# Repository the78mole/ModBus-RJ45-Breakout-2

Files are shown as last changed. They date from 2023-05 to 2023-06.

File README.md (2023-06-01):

# Modbus-RJ45-Breakout
A breakout board for Dual-ModBus-over-Twisted-Pair (RJ45) with isolated converters option

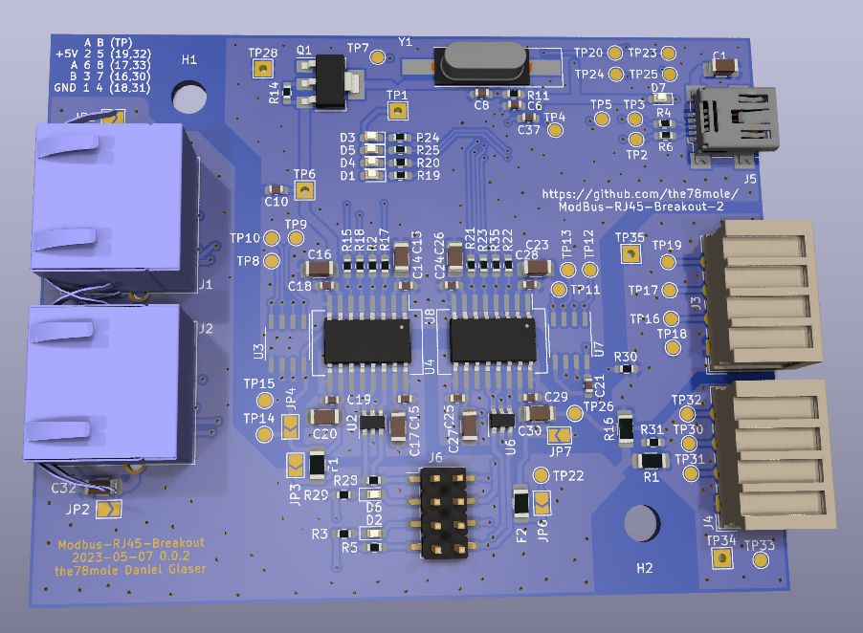
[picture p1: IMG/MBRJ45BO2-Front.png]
Front

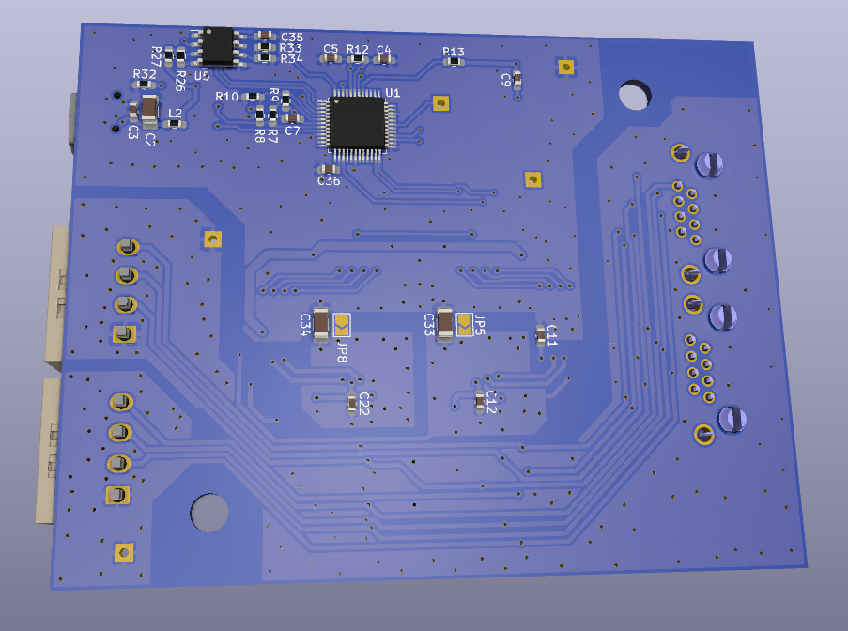
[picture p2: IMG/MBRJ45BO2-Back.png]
Back


Here are some images of the first prototype, assembled with isolating RS485 transceivers. Echo already works, real testing on a ModBus will take place soon.

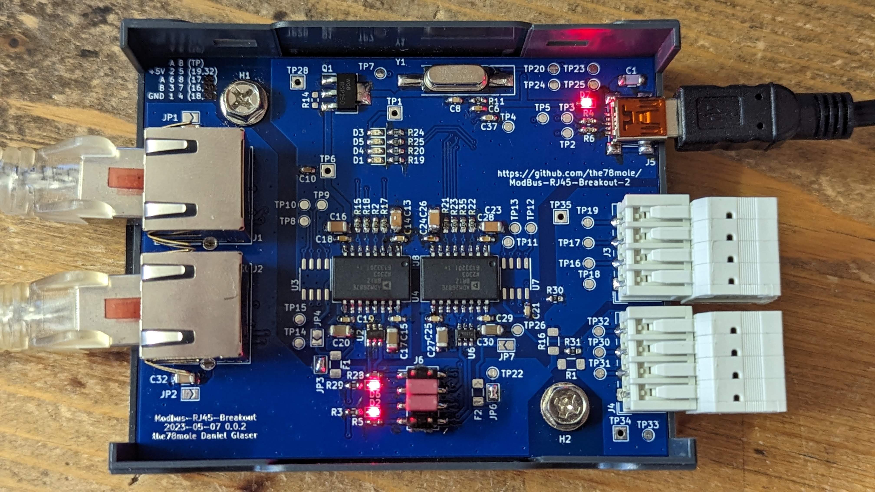
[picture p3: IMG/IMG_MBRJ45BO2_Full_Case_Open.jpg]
Full Case Open

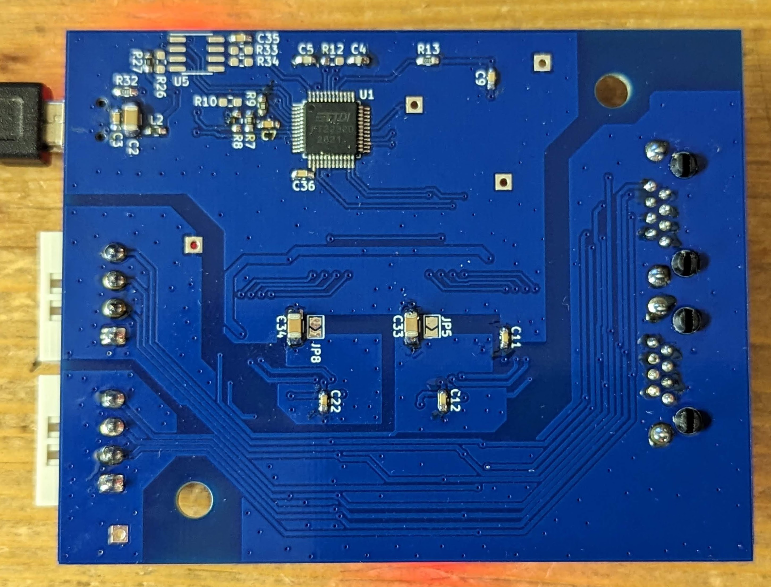
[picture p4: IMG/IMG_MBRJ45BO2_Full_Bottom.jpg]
Full Bottom

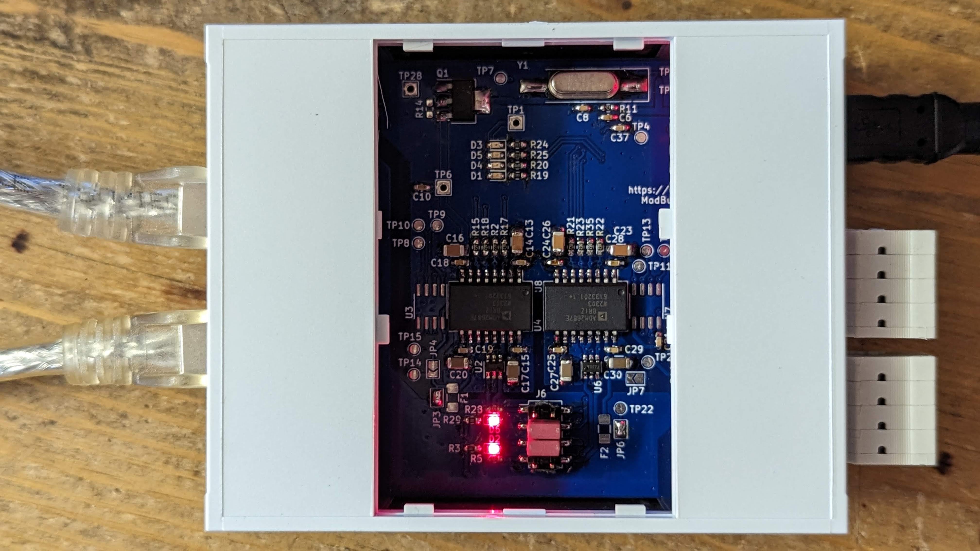
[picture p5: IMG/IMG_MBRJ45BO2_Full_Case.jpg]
Full Case Closed


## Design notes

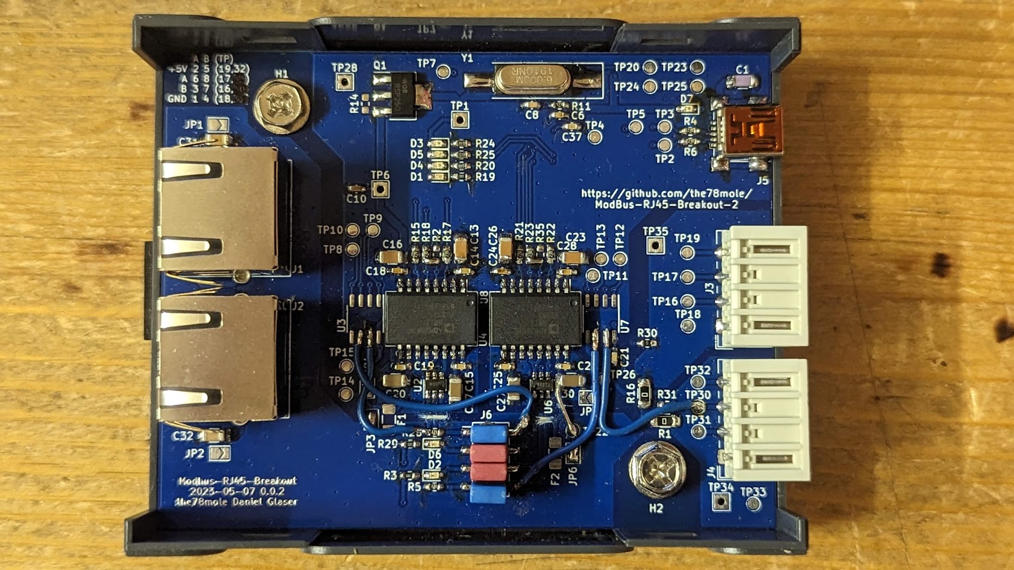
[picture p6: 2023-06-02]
IMG/IMG_MBRJ45BO2_Full_Case_Open-Fixed.jpg

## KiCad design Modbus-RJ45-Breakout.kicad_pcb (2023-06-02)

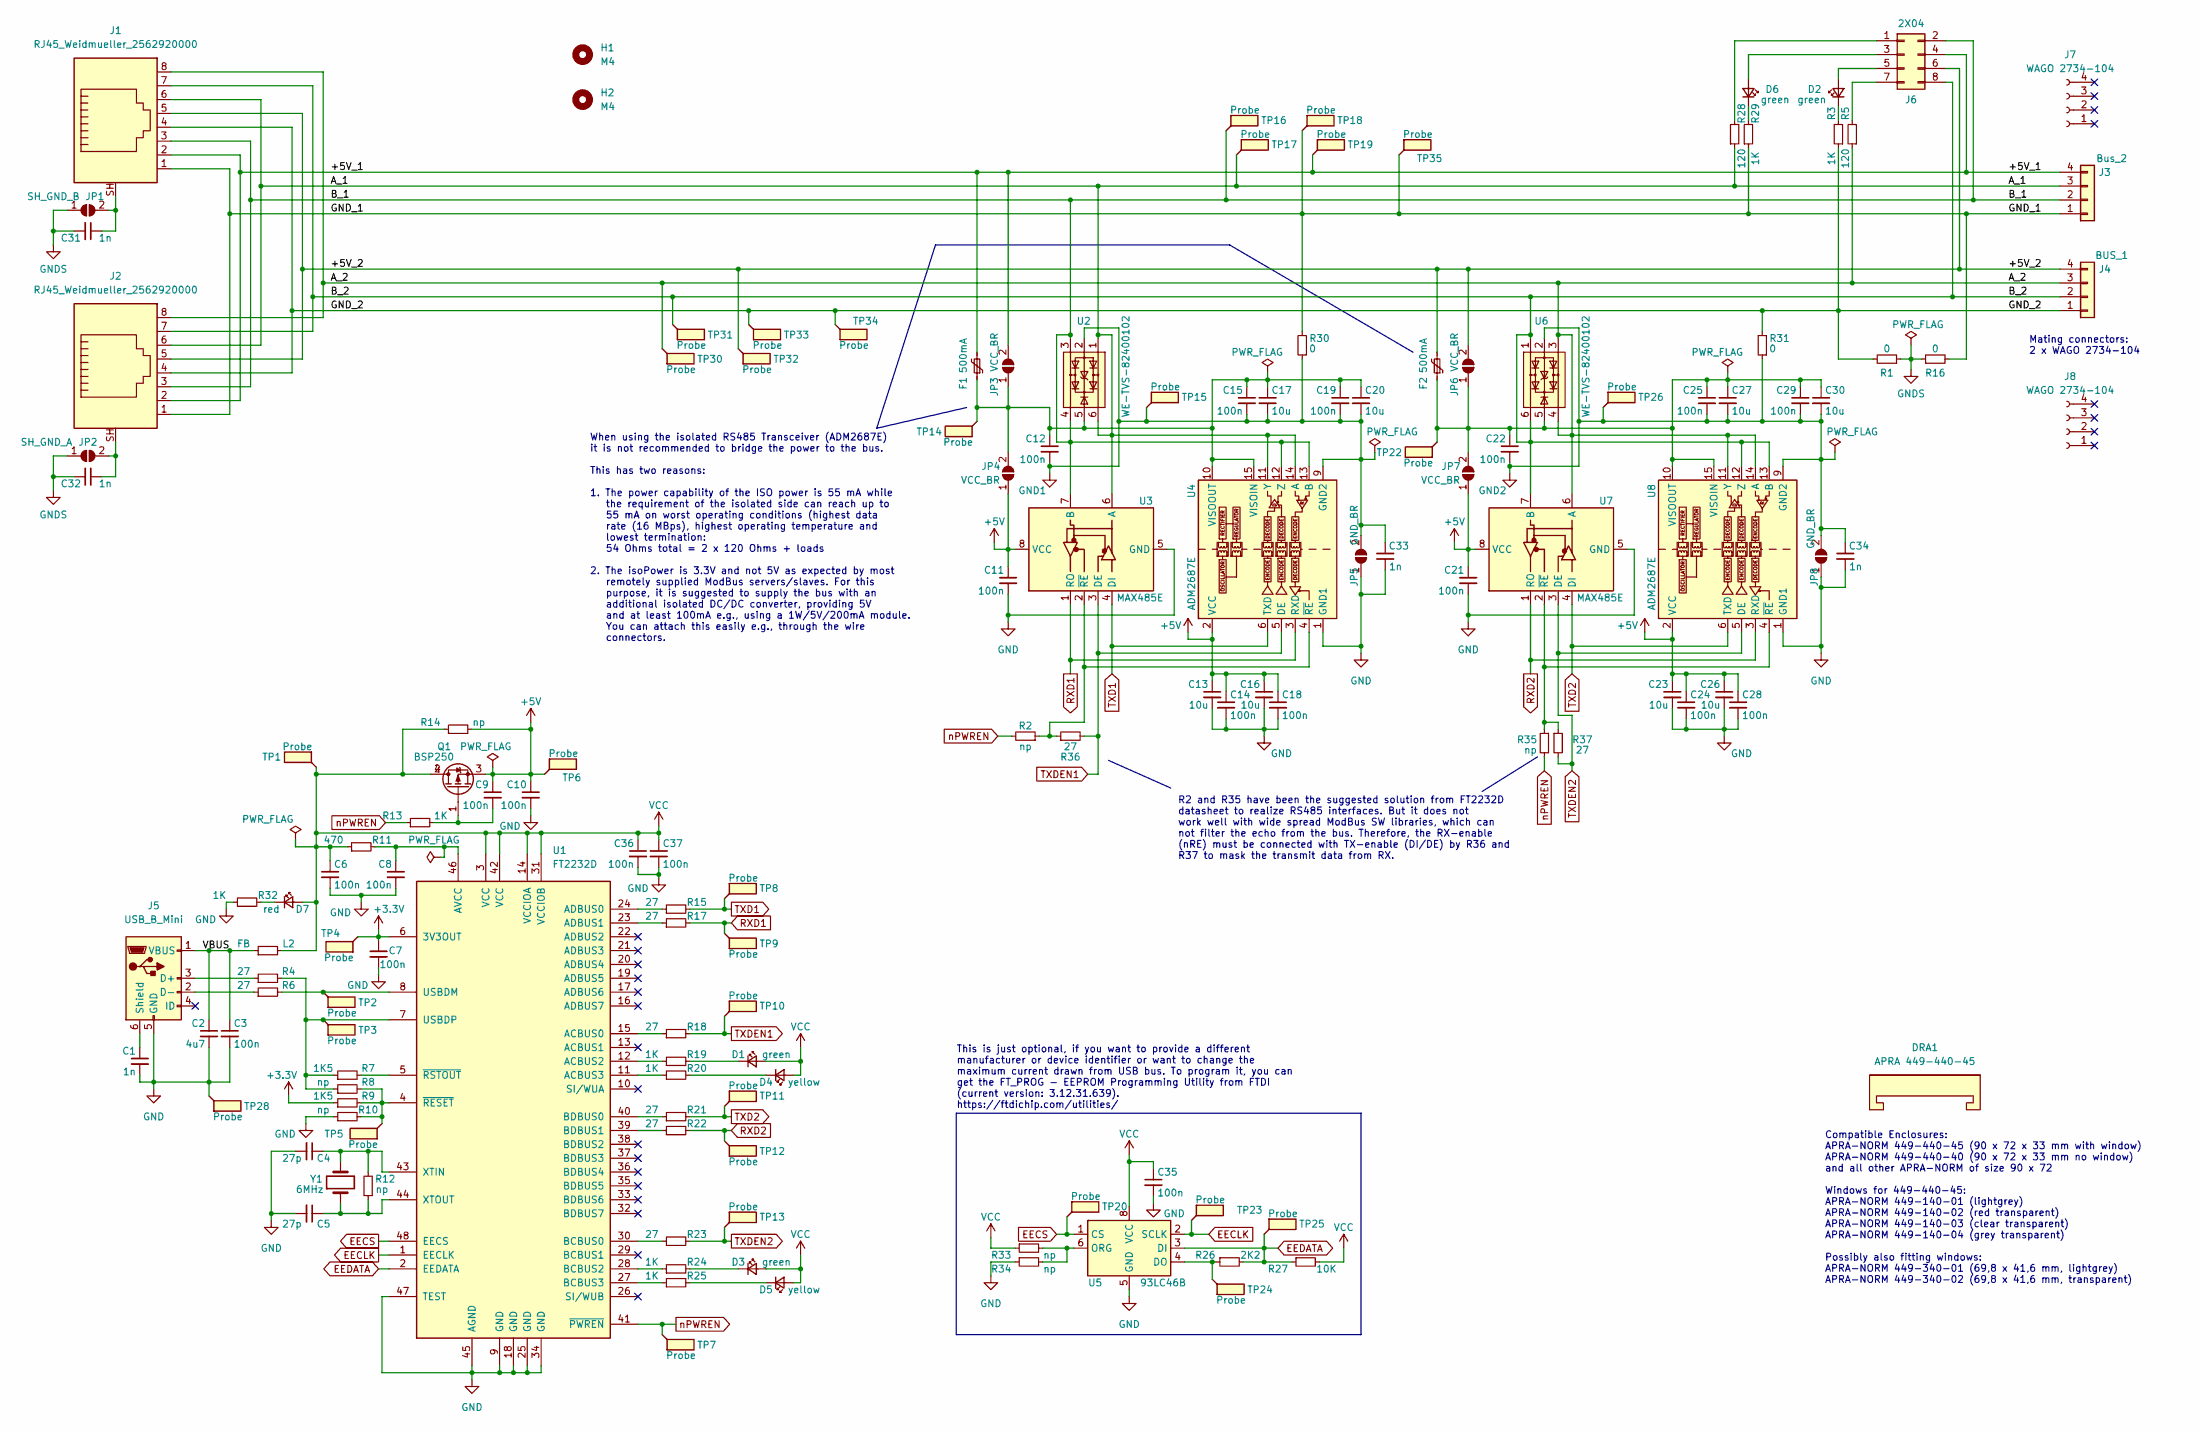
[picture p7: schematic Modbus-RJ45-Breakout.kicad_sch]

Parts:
C1, C31, C32, C33, C34: 1n; C_1206_3216Metric_Pad1.33x1.80mm_HandSolder
C2: 4u7; C_1206_3216Metric_Pad1.33x1.80mm_HandSolder
C3, C6, C7, C8, C9, C10, C11, C12, C14, C15, C18, C19, C21, C22, C24, C25, C28, C29, C35, C36, C37: 100n; C_0603_1608Metric_Pad1.08x0.95mm_HandSolder
C4, C5: 27p; C_0603_1608Metric_Pad1.08x0.95mm_HandSolder
C13, C16, C17, C20, C23, C26, C27, C30: 10u; C_1206_3216Metric_Pad1.33x1.80mm_HandSolder
D1, D2, D3, D6: green; LED_0603_1608Metric_Pad1.05x0.95mm_HandSolder
D4, D5: yellow; LED_0603_1608Metric_Pad1.05x0.95mm_HandSolder
D7: red; LED_0603_1608Metric_Pad1.05x0.95mm_HandSolder
DRA1: APRA 449-440-45; Dummy_0; MPN 449-440-45
F1, F2: 500mA; Fuse_1206_3216Metric_Pad1.42x1.75mm_HandSolder
H1, H2: M4; MountingHole_4.3mm_M4_DIN965
J1, J2: RJ45_Weidmueller_2562920000; RJ45_Weidmüller_2562920000_Horizontal
J3: Bus_2; Wago_734-164_1x04_P3.50mm_Horizontal
J4: BUS_1; Wago_734-164_1x04_P3.50mm_Horizontal
J5: USB_B_Mini; USB_Mini-B_Wuerth_65100516121_Horizontal
J6: 2X04; PinHeader_2x04_P2.54mm_Vertical_SMD
J7, J8: WAGO 2734-104; Dummy_0; MPN 2734-104
JP1: SH_GND_B; SolderJumper-2_P1.3mm_Open_TrianglePad1.0x1.5mm
JP2: SH_GND_A; SolderJumper-2_P1.3mm_Open_TrianglePad1.0x1.5mm
JP3, JP4, JP6, JP7: VCC_BR; SolderJumper-2_P1.3mm_Open_TrianglePad1.0x1.5mm
JP5, JP8: GND_BR; SolderJumper-2_P1.3mm_Open_TrianglePad1.0x1.5mm
L2: FB; R_0603_1608Metric_Pad0.98x0.95mm_HandSolder
Q1: BSP250; SOT-223
R1, R16: 0; R_1206_3216Metric_Pad1.30x1.75mm_HandSolder
R2, R8, R10, R12, R14, R33, R34, R35: np; R_0603_1608Metric_Pad0.98x0.95mm_HandSolder
R3, R13, R19, R20, R24, R25, R29, R32: 1K; R_0603_1608Metric_Pad0.98x0.95mm_HandSolder
R4, R6, R15, R17, R18, R21, R22, R23, R36, R37: 27; R_0603_1608Metric_Pad0.98x0.95mm_HandSolder
R5, R28: 120; R_0603_1608Metric_Pad0.98x0.95mm_HandSolder
R7, R9: 1K5; R_0603_1608Metric_Pad0.98x0.95mm_HandSolder
R11: 470; R_0603_1608Metric_Pad0.98x0.95mm_HandSolder
R26: 2K2; R_0603_1608Metric_Pad0.98x0.95mm_HandSolder
R27: 10K; R_0603_1608Metric_Pad0.98x0.95mm_HandSolder
R30, R31: 0; R_0603_1608Metric_Pad0.98x0.95mm_HandSolder
TP1, TP6, TP28, TP34, TP35: Probe; TestPoint_THTPad_2.0x2.0mm_Drill1.0mm
TP2, TP3, TP4, TP5, TP7, TP8, TP9, TP10, TP11, TP12, TP13, TP14, TP15, TP16, TP17, TP18, TP19, TP20, TP22, TP23, TP24, TP25, TP26, TP30, TP31, TP32, TP33: Probe; TestPoint_Pad_D1.5mm
U1: FT2232D; LQFP-48_7x7mm_P0.5mm
U2, U6: WE-TVS-82400102; SOT-23-6
U3, U7: MAX485E; SO-8_3.9x4.9mm_P1.27mm
U4, U8: ADM2687E; SOIC-16W_7.5x12.8mm_P1.27mm
U5: 93LC46B; SOIC-8_3.9x4.9mm_P1.27mm
Y1: 6MHz; Crystal_SMD_HC49-SD_HandSoldering

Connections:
+3V3: C7.1, R9.1, TP4.1, U1.6 (3V3OUT)
+5V: C9.1, C10.1, C11.1, C13.1, C14.1, C16.1, C18.1, C21.1, C23.1, C24.1, C26.1, C28.1, JP4.1 (A), JP7.1 (A), Q1.3 (S), R14.2, TP6.1, U3.8 (VCC), U4.2 (VCC), U4.7 (VCC), U7.8 (VCC), U8.2 (VCC), U8.7 (VCC)
/+5V_1: F1.2, J1.2, J2.2, J3.4, J6.4, JP3.2 (B), TP19.1
/+5V_2: F2.2, J1.5, J2.5, J4.4, J6.6, JP6.2 (B), TP32.1
/A_1: J1.6, J2.6, J3.3, R28.1, TP17.1, U2.1, U2.6, U3.6 (A), U4.11 (Y), U4.14 (A)
/A_2: J1.8, J2.8, J4.3, R5.1, TP30.1, U6.3, U6.4, U7.6 (A), U8.11 (Y), U8.14 (A)
/B_1: J1.3, J2.3, J3.2, J6.2, TP16.1, U2.3, U2.4, U3.7 (B), U4.12 (Z), U4.13 (B)
/B_2: J1.7, J2.7, J4.2, J6.8, TP31.1, U6.1, U6.6, U7.7 (B), U8.12 (Z), U8.13 (B)
/GND_1: J1.1, J2.1, J3.1, R16.2, R29.1, R30.2, TP18.1, TP35.1
/GND_2: J1.4, J2.4, J4.1, R1.2, R3.1, R31.2, TP33.1, TP34.1
/VBUS: C2.1, C3.1, J5.1 (VBUS), L2.1
EECLK: TP23.1, U1.1 (EECLK), U5.2 (SCLK)
EECS: TP20.1, U1.48 (EECS), U5.1 (CS)
EEDATA: R26.2, R27.1, TP25.1, U1.2 (EEDATA), U5.3 (DI)
GND: C1.2, C2.2, C3.2, C4.2, C5.2, C6.2, C7.2, C8.2, C10.2, C11.2, C13.2, C14.2, C16.2, C18.2, C21.2, C23.2, C24.2, C26.2, C28.2, C33.2, C34.2, C35.2, C36.2, C37.2, J5.5 (GND), JP5.1 (A), JP8.1 (A), R10.1, R32.1, R34.1, TP28.1, U1.9 (GND), U1.18 (GND), U1.25 (GND), U1.34 (GND), U1.45 (AGND), U1.47 (TEST), U3.5 (GND), U4.1 (GND1), U4.8 (GND1), U5.5 (GND), U7.5 (GND), U8.1 (GND1), U8.8 (GND1)
GND1: C12.2, C15.2, C17.2, C19.2, C20.2, C33.1, JP5.2 (B), R30.1, TP15.1, U2.2, U4.9 (GND2), U4.16 (GND2)
GND2: C22.2, C25.2, C27.2, C29.2, C30.2, C34.1, JP8.2 (B), R31.1, TP26.1, U6.2, U8.9 (GND2), U8.16 (GND2)
GNDS: C31.2, C32.2, JP1.1 (A), JP2.1 (A), R1.1, R16.1
unnamed: C1.1, J5.6 (Shield)
unnamed: C4.1, R12.2, U1.43 (XTIN), Y1.2
unnamed: C5.1, R12.1, U1.44 (XTOUT), Y1.1
unnamed: C8.1, R11.2, U1.46 (AVCC)
unnamed: C9.2, Q1.1 (D), R13.2
unnamed: C12.1, C15.1, C17.1, C19.1, C20.1, F1.1, JP3.1 (A), JP4.2 (B), TP14.1, U2.5, U4.10 (VISOOUT), U4.15 (VISOIN)
unnamed: C22.1, C25.1, C27.1, C29.1, C30.1, F2.1, JP6.1 (A), JP7.2 (B), TP22.1, U6.5, U8.10 (VISOOUT), U8.15 (VISOIN)
unnamed: C31.1, J1.SH, JP1.2 (B)
unnamed: C32.1, J2.SH, JP2.2 (B)
unnamed: D1.1 (K), R19.2
unnamed: D2.1 (K), R3.2
unnamed: D2.2 (A), J6.5
unnamed: D3.1 (K), R24.2
unnamed: D4.1 (K), R20.2
unnamed: D5.1 (K), R25.2
unnamed: D6.1 (K), R29.2
unnamed: D6.2 (A), J6.3
unnamed: D7.1 (K), R32.2
unnamed: J5.2 (D-), R6.1
unnamed: J5.3 (D+), R4.1
unnamed: J6.1, R28.2
unnamed: J6.7, R5.2
unnamed: R2.1, R36.1, U3.2 (~RE), U4.4 (~RE)
unnamed: R4.2, R7.1, R8.1, TP3.1, U1.7 (USBDP)
unnamed: R6.2, TP2.1, U1.8 (USBDM)
unnamed: R7.2, U1.5 (~RSTOUT)
unnamed: R8.2, R9.2, R10.2, TP5.1, U1.4 (~RESET)
unnamed: R15.1, U1.24 (ADBUS0)
unnamed: R17.1, U1.23 (ADBUS1)
unnamed: R18.1, U1.15 (ACBUS0)
unnamed: R19.1, U1.12 (ACBUS2)
unnamed: R20.1, U1.11 (ACBUS3)
unnamed: R21.1, U1.40 (BDBUS0)
unnamed: R22.1, U1.39 (BDBUS1)
unnamed: R23.1, U1.30 (BCBUS0)
unnamed: R24.1, U1.28 (BCBUS2)
unnamed: R25.1, U1.27 (BCBUS3)
unnamed: R26.1, TP24.1, U5.4 (DO)
unnamed: R33.2, R34.2, U5.6 (ORG)
unnamed: R35.1, R37.1, U7.2 (~RE), U8.4 (~RE)
RXD1: R17.2, TP9.1, U3.1 (RO), U4.3 (RXD)
RXD2: R22.2, TP12.1, U7.1 (RO), U8.3 (RXD)
TXD1: R15.2, TP8.1, U3.4 (DI), U4.6 (TXD)
TXD2: R21.2, TP11.1, U7.4 (DI), U8.6 (TXD)
TXDEN1: R18.2, R36.2, TP10.1, U3.3 (DE), U4.5 (DE)
TXDEN2: R23.2, R37.2, TP13.1, U7.3 (DE), U8.5 (DE)
VCC: C6.1, C35.1, C36.1, C37.1, D1.2 (A), D3.2 (A), D4.2 (A), D5.2 (A), D7.2 (A), L2.2, Q1.2 (G), Q1.4 (G), R11.1, R14.1, R27.2, R33.1, TP1.1, U1.3 (VCC), U1.14 (VCCIOA), U1.31 (VCCIOB), U1.42 (VCC), U5.8 (VCC)
nPWREN: R2.2, R13.1, R35.2, TP7.1, U1.41 (~PWREN)

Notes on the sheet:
Compatible Enclosures: APRA-NORM 449-440-45 (90 x 72 x 33 mm with window) APRA-NORM 449-440-40 (90 x 72 x 33 mm no window) and all other APRA-NORM of size 90 x 72 Windows for 449-440-45: APRA-NORM 449-140-01 (lightgrey) APRA-NORM 449-140-02 (red transparent) APRA-NORM 449-140-03 (clear transparent)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
When using the isolated RS485 Transceiver (ADM2687E) it is not recommended to bridge the power to the bus. This has two reasons: 1. The power capability of the ISO power is 55 mA while the requirement of the isolated side can reach up to 55 mA on worst operating conditions (highest data rate (16 MB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
Mating connectors: 2 x WAGO 2734-104
This is just optional, if you want to provide a different manufacturer or device identifier or want to change the maximum current drawn from USB bus. To program it, you can get the FT_PROG - EEPROM Programming Utility from FTDI (current version: 3.12.31.639). https://ftdichip.com/utilities/
R2 and R35 have been the suggested solution from FT2232D datasheet to realize RS485 interfaces. But it does not work well with wide spread ModBus SW libraries, which can not filter the echo from the bus. Therefore, the RX-enable (nRE) must be connected with TX-enable (DI/DE) by R36 and R37 to mask 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

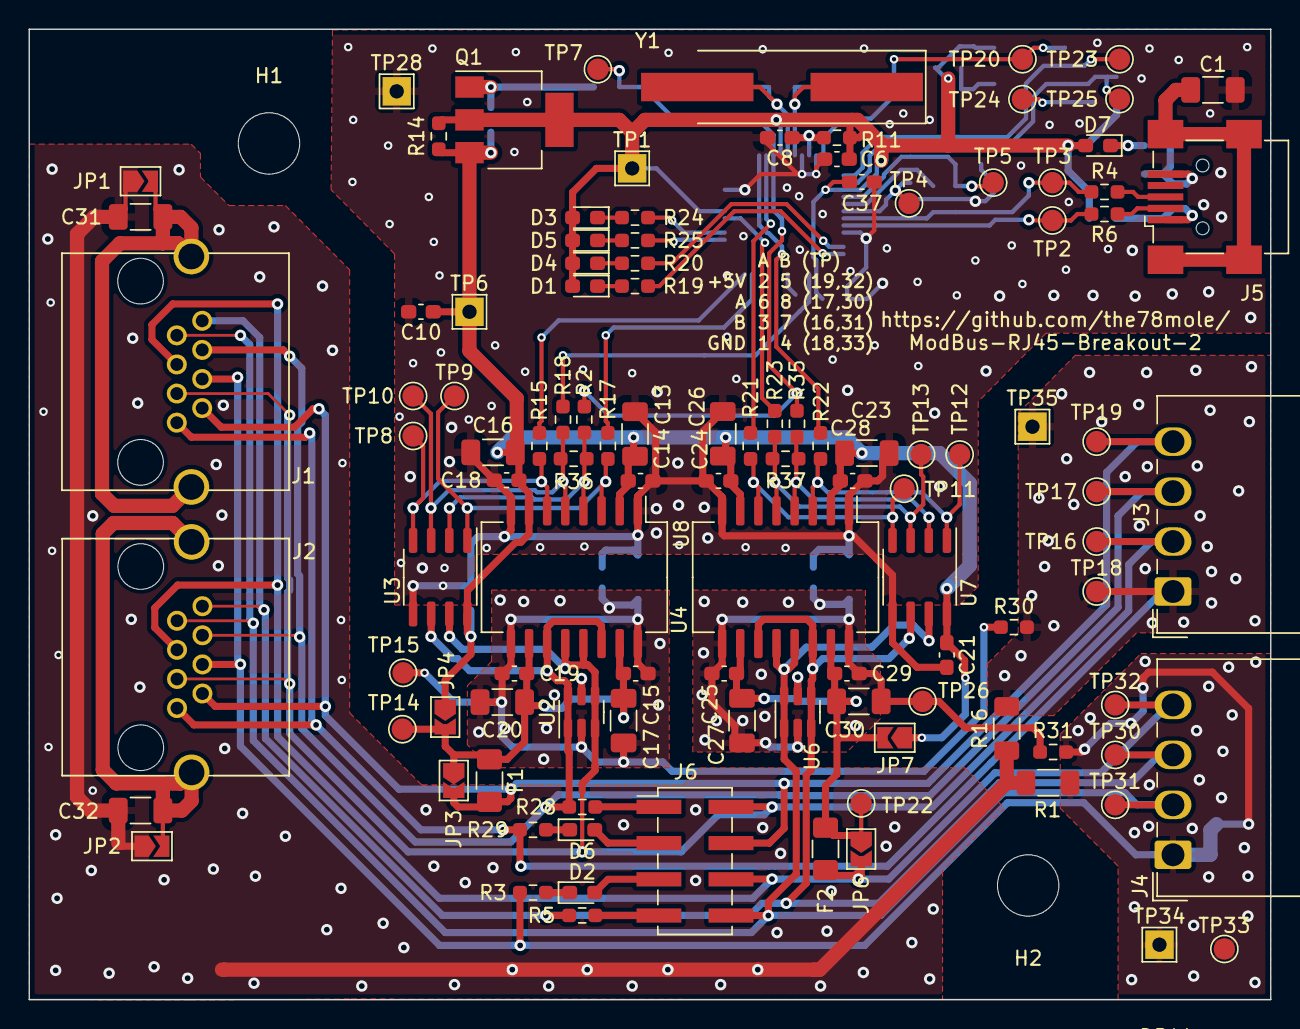
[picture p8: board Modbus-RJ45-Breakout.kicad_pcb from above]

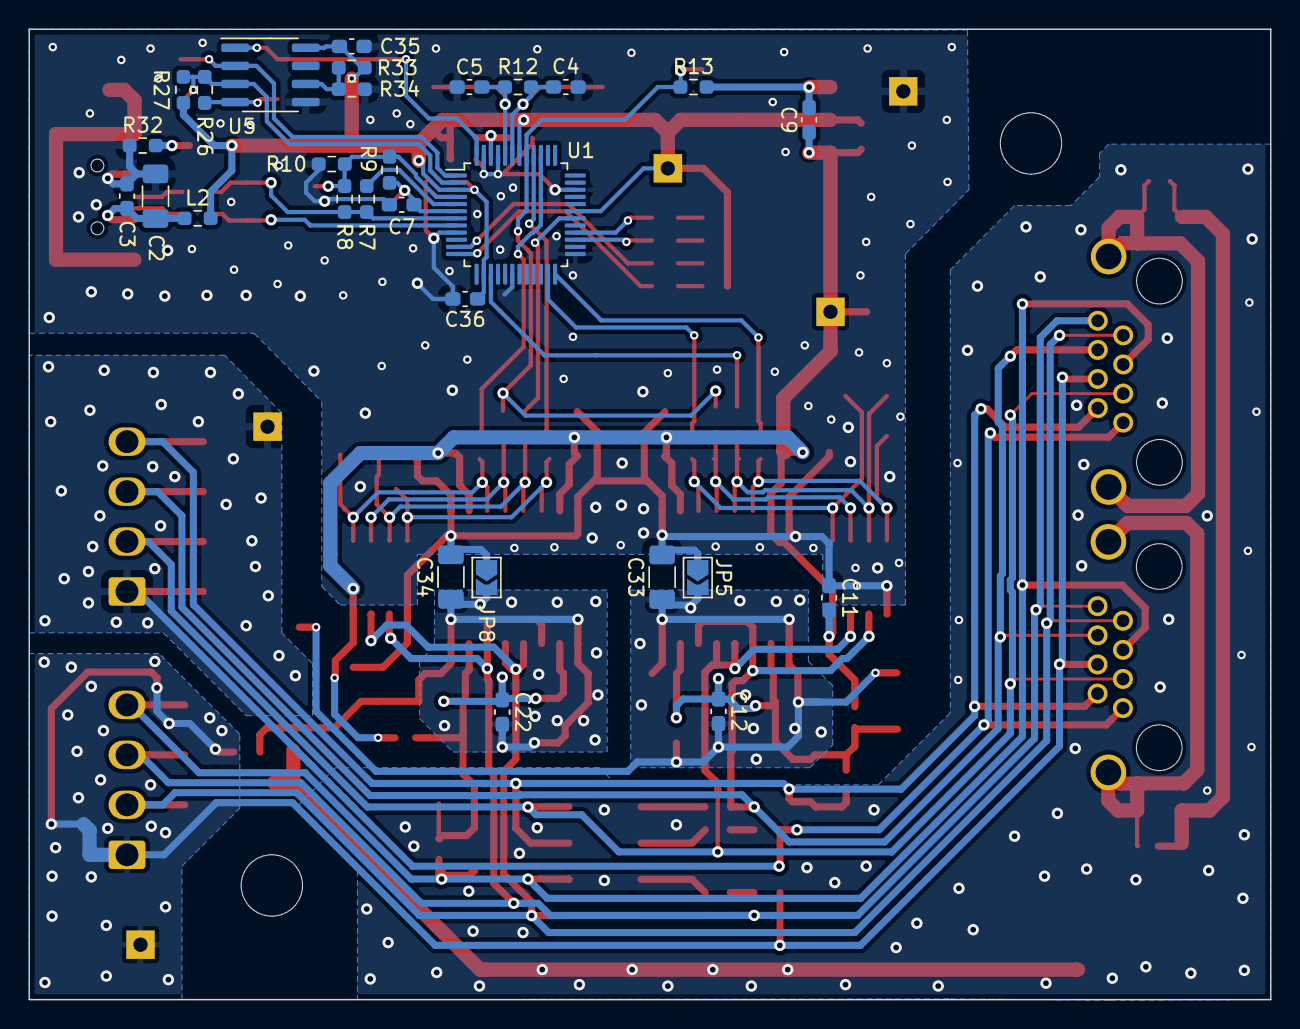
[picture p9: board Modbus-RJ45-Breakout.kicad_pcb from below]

Board: 2 copper layers, 87.0 x 68.0 mm, 145 parts (29 on the bottom side), 66 nets.

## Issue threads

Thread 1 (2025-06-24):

TP30, TP31 & TP33 are wrongly described

the78mole, 2025-06-24:
The silksreen docs in the topmost left corener on front side should be:
```txt
     A  B  (TP)
+5V  2  5  (19,32)
  A  6  8  (17,30)
  B  3  7  (16,31)
GND  1  4  (18,33)
```

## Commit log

2023-05-07 Moved the USB-Power LED to a more central position
    Since many cases have their clear view window in the center,
    I moved the USB Power LED also there to be easily visible.
    [Modbus-RJ45-Breakout.kicad_pcb]
2023-05-07 Removed unused Schamtic sheets
    These have been the 2 USB converters in the older design
    and are not needed anymore. Everything is contained in
    the A3 main sheet.
    [USB.kicad_sch, USB2.kicad_sch]
2023-05-19 Partly improved and re-routed
    [Modbus-RJ45-Breakout.kicad_pcb, Modbus-RJ45-Breakout.kicad_sch]
2023-05-20 As ordered, added info on enclosures
    [Modbus-RJ45-Breakout.kicad_pcb, Modbus-RJ45-Breakout.kicad_sch]
2023-05-30 Fixed TP docs on PCB and added ibom
    [Modbus-RJ45-Breakout.kicad_pcb, Modbus-RJ45-Breakout.kicad_sch]
2023-06-01 Adjustments during prototype build
    [Modbus-RJ45-Breakout.kicad_sch]
2023-06-01 Added some prototype images
2023-06-01 Moved the terminal docs to the middle of the PCB
    ...to be able to read it through the cut out of the case.
    [Modbus-RJ45-Breakout.kicad_pcb]
2023-06-01 RS485 bus echo solved and A<->B swap with ISO Transceivers (schematic only)
    This can be solved also with the current PCB by swapping the A and B externally
    and not mixing ISO and non-ISO bus transceivers. The RX-Enable problem can be solved
    by a desoldering R2 and R35 and bridging the pads to R18 and R23 resp. close to the transceiver.
    [Modbus-RJ45-Breakout.kicad_sch]
2023-06-02 Fixed all issues and added Gerber exports
    [Modbus-RJ45-Breakout-B_Cu.gbr, Modbus-RJ45-Breakout-B_Mask.gbr, Modbus-RJ45-Breakout-B_Paste.gbr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]
2023-06-02 Version bump 1.0.0
    [Modbus-RJ45-Breakout.kicad_pcb, Modbus-RJ45-Breakout.kicad_sch]
2023-06-02 Added an image of a fixed 0.0.2 board
2025-09-12 feat: add automated KiCad production files workflow (#2)
    * feat: add KiCad production files workflow and scripts
    * docs: add production workflow documentation and update gitignore
    * Add Renovate configuration file
    ---------
2025-10-12 Fix release job artifact naming mismatch causing release assets to be missing (#3)
    * Fix release artifact naming mismatch: use correct KiCad project filenames
    * Improve release artifact handling: add manufacturing package download and use robust file search
    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
